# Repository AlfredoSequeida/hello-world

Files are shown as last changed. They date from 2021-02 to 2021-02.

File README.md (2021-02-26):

[Check out the video!](https://youtu.be/ratVGRWkmX0)

# Hello world!

Hello world image demo



This is a 3d printed "hello world!" sign powered by the L0L1n/NodeMCU V3 board, which hosts the ESP8266E board. All of the code, schematics, openSCAD (3D model), and mechanical drawings for the project are open-source for you to modify however you want.

## The model
The model for this design was made using openSCAD. Each letter is meant to be printed individually and then glued together. Because of this, each letter has been split into a module in the openSCAD code. Each letter is between 59.9mm and 205.10mm in length, 184.10mm and 193.3mm in width and 50mm in height in horizontal (laying down) orientation. This model was built with the thought in mind of mounting the letters on a wall, which is why 4 of the letters ("h", "o1", "w", "!", where a letter followed by an integer defines the letter in position to the whole phrase "hello world". Making "o1" the first "o" in "hello") have holes for a screw or nail. With that said, with the letters mounted on the wall split into two rows of the words "hello" and "world!", this entire sign measures a maximum of 790.5mm X 384.2mm X 50 mm (l X w X h) with the letters standing up mounted on a wall.

Every model also has an insert, which is a very thin copy of the letter with half the laying down height which serves as both a cover and a light defuser for the LEDs:

Insert Demo

The inserts fit snug into the letters with a 0.5mm gap, however, you might want to use some sandpaper or a file to create a little more room for letters like the "e", "o", and "d", which have center cutouts since those parts might be a bit more difficult to fit easily.

## Modifying the model
If you want to change the size of the model, this can easily be achieved by changing the attributes at the top of the openSCAD code. All of the measurements are unitless, but mm should be used as those are the units used to measure the electrical components.

`font_size`: The size of the font.

`height`: The height/depth of the model laying down +10mm, so 40mm makes the depth 50mm.

`wall`: The thickness of the walls -5mm, so 10mm makes the walls 5mm thick.

If the size is adjusted, the position of the LED pass through-holes should be modified as well. The same applies to the horizontal and vertical positions of the letters (`h_x`, `w_y`, etc).

The strange adding and subtracting of magical numbers in the measurements is due to the way the walls were created with [openSCAD'S Minkowski method](https://en.wikibooks.org/wiki/OpenSCAD_User_Manual/Transformations#minkowski).

## Printing the model
In the build for the video, this model was printed using a [Creality Ender3 V2](https://www.amazon.com/Creality-Meanwell-Motherboard-Carborundum-Platform/dp/B08D65ZH5W) with an extruder temperature of 225°C and base temperature of 70°C. Using 5% infill with a wall height of 0.28mm using white Inland PLA+. Each Letter took a maximum of 20 hours to print (the "w" took the longest time) and each insert took about 3 hours to print.

## The Parts used
The following parts (electrical components) were used for this build:
- (2) [WS2812B LED Strip 5m 60leds/m](https://www.amazon.com/BTF-LIGHTING-Flexible-Individually-Addressable-Non-waterproof/dp/B01CDTEJBG)
- (1) [LOL1n/NodeMCU V3 (ESP8266E) board](https://www.amazon.com/HiLetgo-Internet-Development-Wireless-Micropython/dp/B010N1SPRK)
- (1) [LM2596S DC-DC 3A Buck Adjustable Step-down Power Supply Converter Module](https://www.amazon.com/Adjustable-Converter-1-5-35v-Efficiency-Regulator/dp/B07QKHR6PY) Used to step down the voltage to 5V if using a power supply larger than 5V.
- (1) [DC Female adapter](https://www.amazon.com/Ksmile®-Female-2-1x5-5mm-Adapter-Connector/dp/B015OCV5Y8)
- (1) [300 - 500 ohm resistor or combination of resistors to make the needed sum](https://www.amazon.com/Elegoo-Values-Resistor-Assortment-Compliant/dp/B072BL2VX1) To protect the first LED when controlling the strip.
- Wire, soldering iron, solder, shrink tube, and connectors to put everything together. With the exception of the wiring, the other parts are optional but recommended.

Included in the assets directory are SVG [schematics](https://github.com/AlfredoSequeida/hello-world/blob/main/assets/schematics.svg) for putting the parts together and [mechanical drawings](https://github.com/AlfredoSequeida/hello-world/blob/main/assets/mechanical_drawings.svg) for the parts. Since they are SVG files, you can open them using a vector editing program like [inkscape](https://inkscape.org/) or a modern web browser and zoom in very close without losing detail.

## The software
The software is controlled via the web interface hosted by the server on the ESP8266 board. To get the software on the board, it needs to be compiled and uploaded to the board using the [Arduino IDE](https://github.com/arduino/Arduino) or [arduino-cli](https://github.com/arduino/arduino-cli). To do this, you must install the [ESP8266 core for Arduino](https://github.com/esp8266/Arduino) and these other dependencies not included with the ESP8266 core:

- [ArduinoJson](https://github.com/bblanchon/ArduinoJson): Used for handling the data sent via HTTP from the web application.
- [FastLED](https://github.com/FastLED/FastLED) : Used to control the LED strip.

The code should also be modified using your local network's (WiFi) AP name and password. This can be set by modifying the character pointers `const char* ssid` and `const char* password`.

Then the LEDs can be controlled using the web interface accessible using a web browser using the IP address of the ESP8266 board after it has been connected to your network.

## The web interface
Web Interface Demo

The web interface is how you can control the LED colors, gradients, and animations of the LEDs. The interface is pretty self-explanatory, however, some of the logic behind it might be useful to explain for modification purposes. All of the HTML, CSS, and JavaScript for the web app can be found in the [index.h](https://github.com/AlfredoSequeida/hello-world/blob/main/ESP8266/LEDController/index.h) file.

The gradients used for the lights are dynamically created at run time and are made using the CSS linear-gradient() function. This makes it easy to create gradients using CSS instead of using FastLED's method for creating gradients. The conversion to something FastLED can understand is handled using JavaScript and then sent over an HTTP POST request to the server as a JSON object with the following format to the `/set-gradient-color` endpoint.

```
{
   "gradient":[
      [
         0,
         255,
         0,
         0
      ],
      [
         255,
         0,
         0,
         255
      ]
   ],
   "brightness":255,
   "animated":true
}
```

`gradient`: Array of arrays containing FastLED formatted gradient.

`brightness` : Integer containing FastLED formatter brightness value.

`animated`: Boolean value declaring if the gradient should be animated or not.

Thank you to Simon R. for his open-source project [pickr](https://github.com/Simonwep/pickr), which provides the color picker for the web app.

## Other notes
The wiring can be made a lot cleaner by rerouting the DC power input to the "W", where all of the electronic components are mounted. However, for my purposes, the exclamation point made a better location for the power input.

You can also use other LED strips, however, the software will need to be modified, and the [chipset must be supported by FastLED](https://github.com/FastLED/FastLED/wiki/Overview#chipsets). Note that the LEDs used in this project were used because they are individually addressable meaning that each LED can be controlled independently of the others, making it possible to create moving animations and gradients with the LEDs.

The font used for the model is [Nooble Wooble](https://www.dafont.com/nooble-wooble.font)

DISCLAIMER: Links included might be affiliate links. If you purchase a product with the links that I provide, I may receive a small commission. There is no additional charge to you!

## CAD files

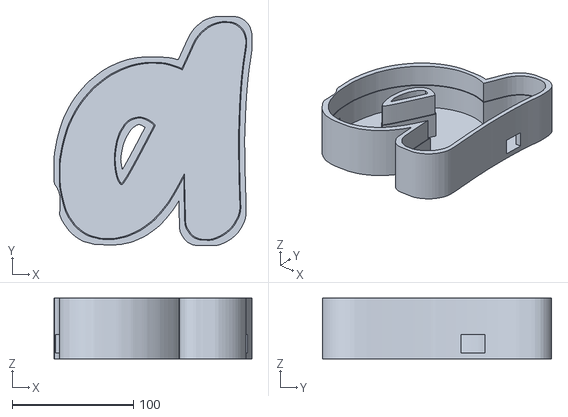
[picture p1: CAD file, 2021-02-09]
models/d.stl
163.3 x 189.0 x 50.0

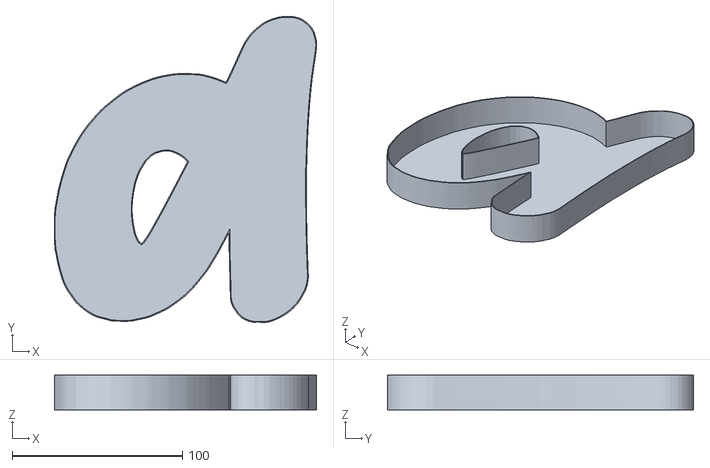
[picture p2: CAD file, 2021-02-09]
models/d_insert.stl
154.2 x 179.9 x 20.4

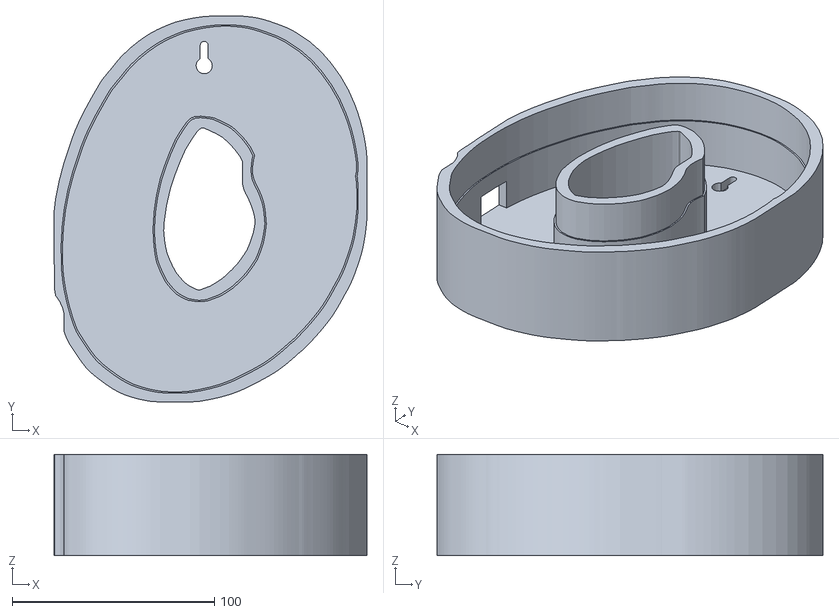
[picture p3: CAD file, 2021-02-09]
models/o1.stl
154.7 x 190.9 x 50.0

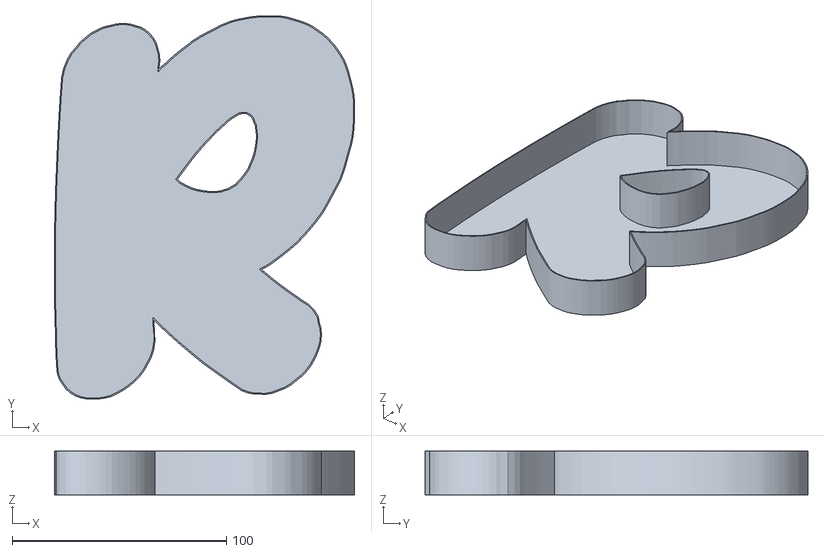
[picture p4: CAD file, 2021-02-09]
models/r_insert.stl
140.1 x 178.6 x 20.4

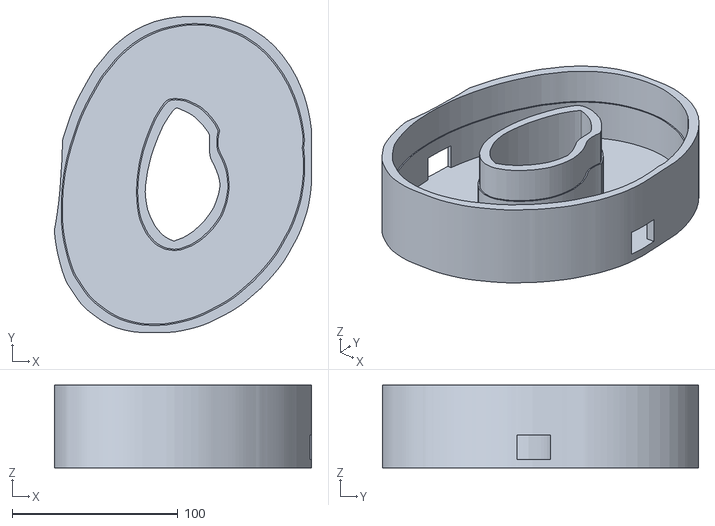
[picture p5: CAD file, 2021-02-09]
models/o.stl
155.4 x 190.9 x 50.0

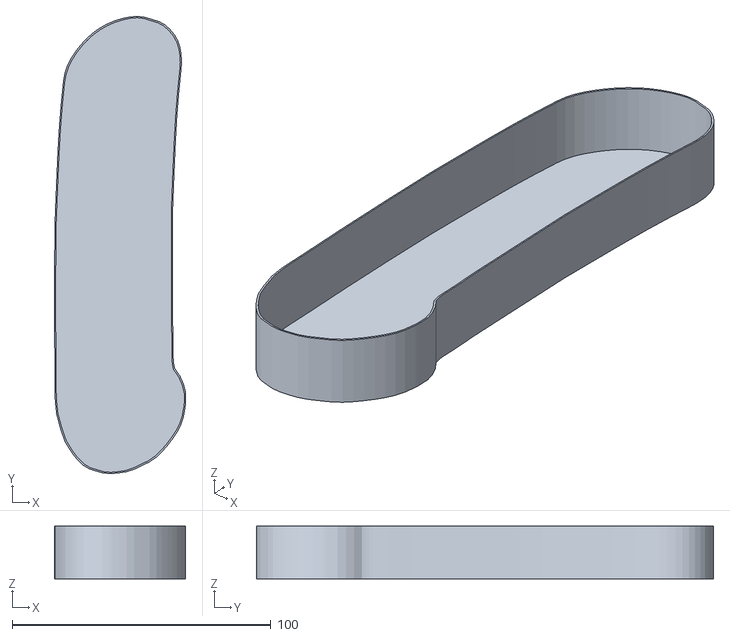
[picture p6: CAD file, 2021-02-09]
models/l1_insert.stl
50.6 x 176.6 x 20.4

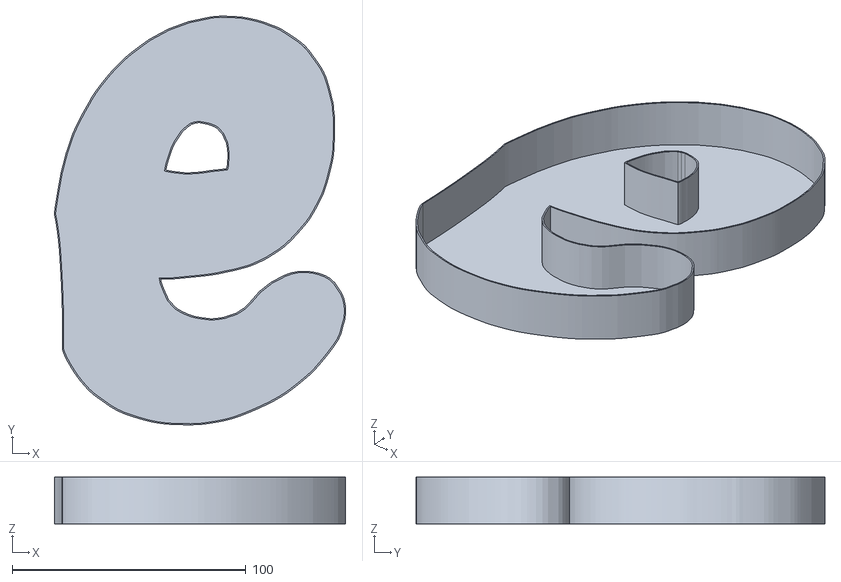
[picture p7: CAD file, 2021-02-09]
models/e_insert.stl
124.6 x 175.0 x 20.0

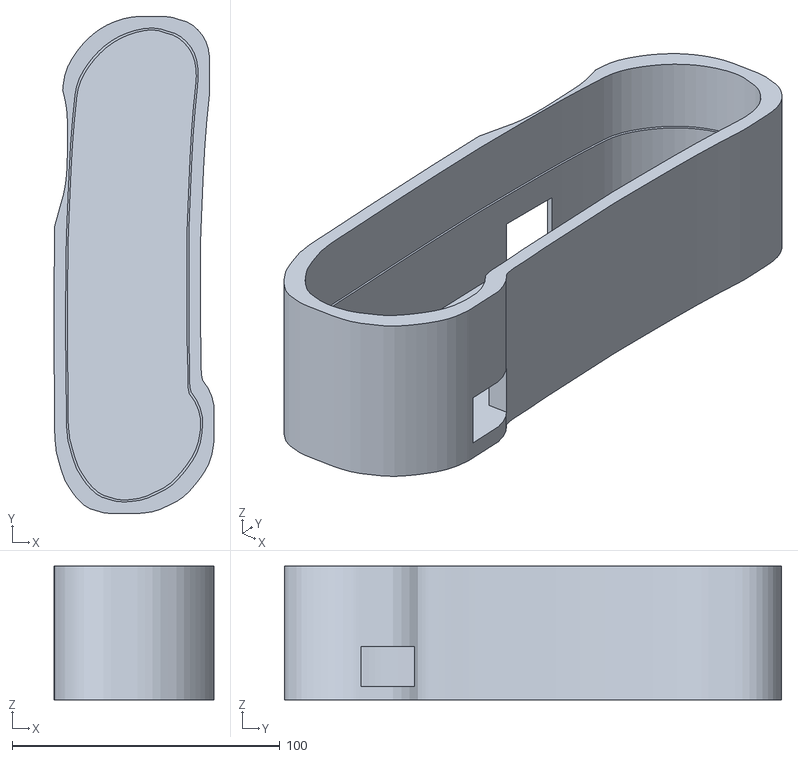
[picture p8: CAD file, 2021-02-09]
models/l3.stl
59.7 x 185.7 x 50.0

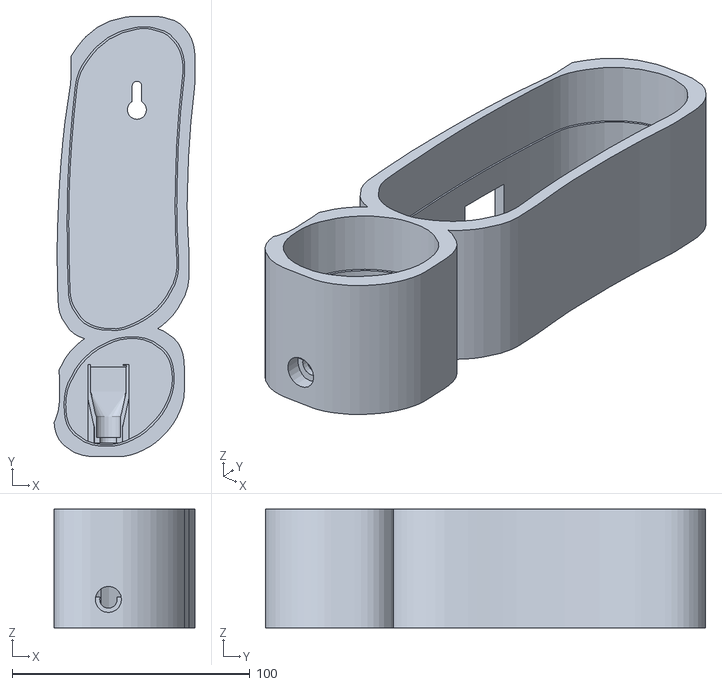
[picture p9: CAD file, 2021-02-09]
models/exclamation.stl
59.3 x 185.0 x 50.0

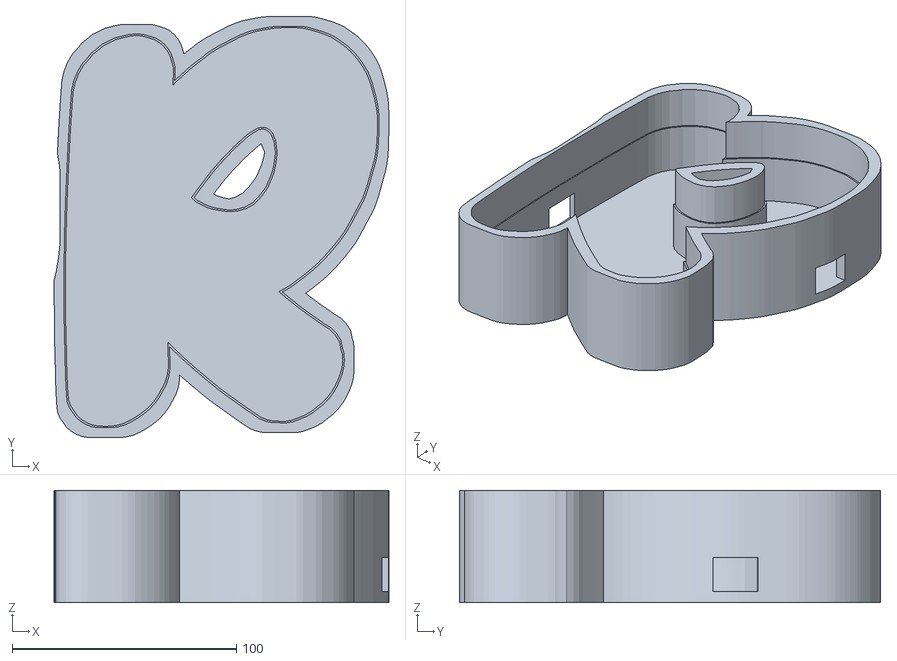
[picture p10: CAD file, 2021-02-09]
models/r.stl
149.2 x 187.7 x 50.0

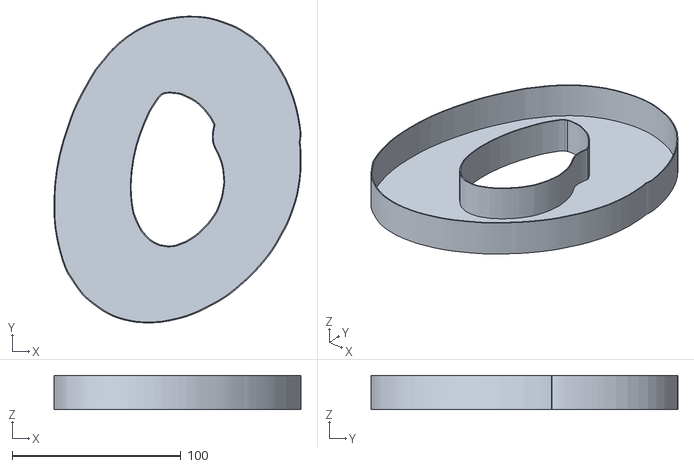
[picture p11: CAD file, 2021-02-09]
models/o2_insert.stl
146.4 x 181.8 x 20.4

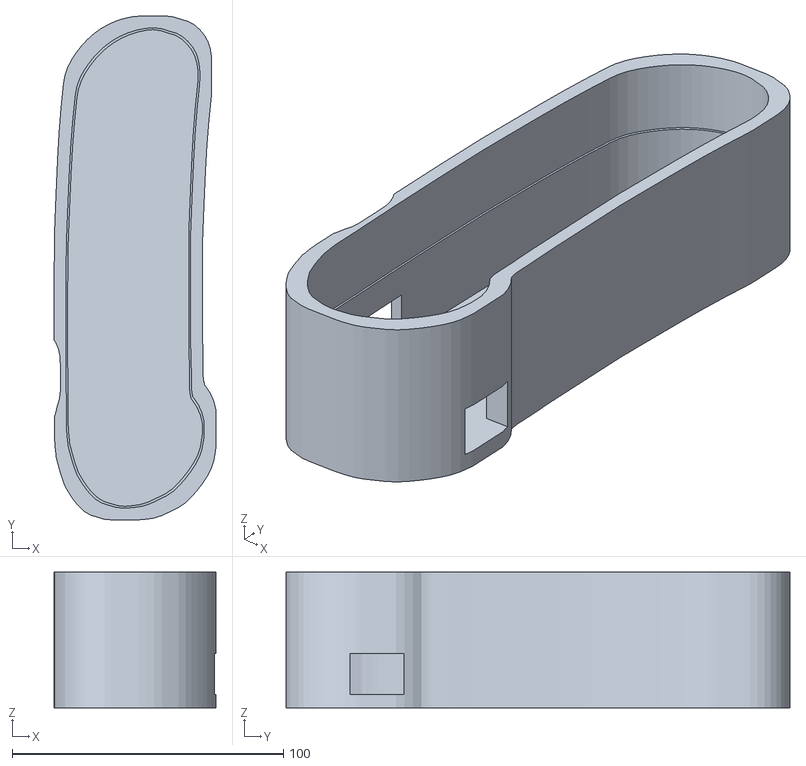
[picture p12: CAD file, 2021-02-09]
models/l1.stl
59.7 x 185.7 x 50.0

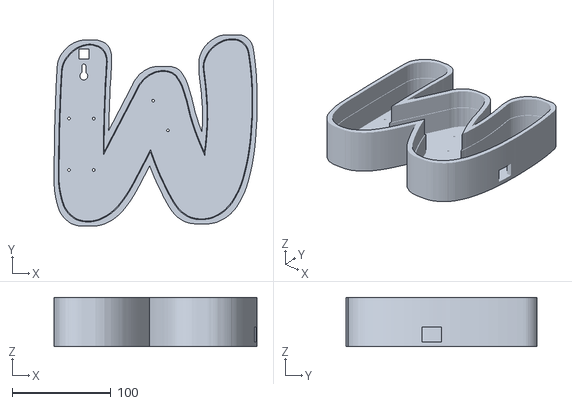
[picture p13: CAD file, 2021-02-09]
models/w.stl
205.1 x 193.3 x 50.0

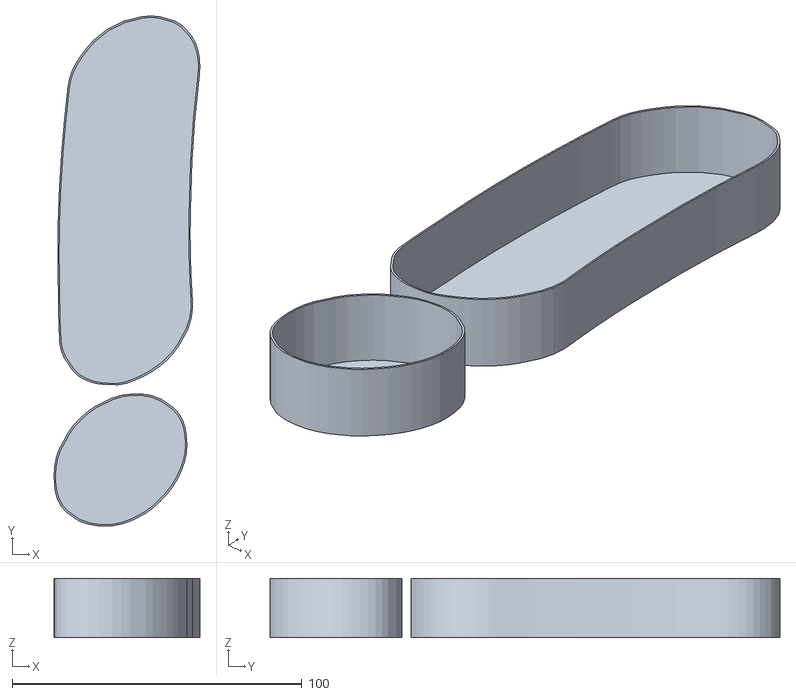
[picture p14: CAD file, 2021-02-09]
models/exclamation_insert.stl
50.3 x 175.9 x 20.4

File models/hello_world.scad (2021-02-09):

$fn = 20;

font = "Nooble Wooble";
height = 40;
font_size = 180;

wall = 10;

// inserts
// adding 0.1 because different letters have different
// curves and thicknesses, so 0.1 allows some room for that
// the excess can be trimmed after printing if necessary.

insert_wall = 0.8 + 0.1;
insert_height = height/2;
insert_support_wall_sub = 1;

// distance difference for insert support = 1 mm
// this leaves a gap of insert 
// wall - 1.3mm leaves 0.5mm gap for the 0.8mm insert

support_wall_sub = wall - 1.3;

// bottom letters are thicker to support
// the top letters

bottom_height = height *2;

led_length = 20;
led_width = 30;
//led_height = height;
led_height = 15;

//cable pass trhough hole from top to bottom
pass_through_length = 10;
pass_through_width = 10;

h_x = 0;
e_x = 135;
l1_x = 268;
l2_x = 325;
o1_x = 379;

w_y = -190;
w_z = 0;

o2_x = 200;
o2_y = w_y; 

r_x = 353;
r_y = w_y;

l3_x = 497;
l3_y = w_y;

d_x = 552;
d_y = w_y;

exclamation_x = 703;
exclamation_y = w_y;

wall_mount_y_top = 120;
wall_mount_y_bottom = -85;

h();
//e();
//l1();
//l2();
//o1();

//w();
//o2();
//r();
//l3();
//d();
//exclamation();

//inserts
//h_insert();
//e_insert();
//l1_insert();
//l2_insert();
//o1_insert();

//w_insert();
//o2_insert();
//r_insert();
//l3_insert();
//d_insert();
//exclamation_insert();

// wall mount test
//difference(){
//    cube([20,20,5]);
//    translate([10,6,0])
//    wall_mount_hole();
//}

//lol1n hole test
//difference(){
//    cube([30,60,5]);
//    
//    translate([2.5,4,0])
//    lol1n_holes();
//}

module h(){
    difference(){
        letter("h",
               font,
               font_size,
               height,
               wall,
               support_wall_sub);
        
        translate([e_x - led_width/2 ,15,0])
        cube([led_width,led_length,led_height]);
        
        translate([20,-38,- wall])
        cube([pass_through_width,
              pass_through_length,
              height]);
        
        translate([25,wall_mount_y_top,0])
        wall_mount_hole();
    }
}

module h_insert(){
    letter("h",
       font,
       font_size,
       height,
       insert_wall);
}

module e(){
    difference(){
        // h and e cross section
        translate([e_x,0,0])
        letter("e",
               font,
               font_size,
               height,
               wall,
               support_wall_sub);
        
        letter("h",
               font,
               font_size,
               height,
               wall,
               support_wall_sub,
               hollow=false);
        
        translate([l1_x - led_width/2 ,0,0])
        cube([led_width,led_length,led_height]);
    }
}

module e_insert(){
    difference(){
        minkowski(){
            difference(){
                translate([e_x,0,0])
                make_text("e",
                          font,
                          font_size,
                          insert_height);

                letter("h",
                       font,
                       font_size,
                       height,
                       wall,
                       hollow=false);
            }
            
            cube(insert_wall, center=true);
        }
        
    minkowski(){
        difference(){
            translate([e_x,0,0])
            make_text("e",
                      font,
                      font_size,
                      insert_height);

            letter("h",
                   font,
                   font_size,
                   height,
                   wall,
                   hollow=false);
            }

    }
        translate([font_size*2 - font_size*2/2,
                   0,
                   height/2])
        cube([font_size*2,font_size*2,insert_wall+0.001],true);
    }
}

module l1(){
    difference(){
        // h and e cross section
        translate([l1_x,0,0])
        letter("l",
               font,
               font_size,
               height,
               wall,
               support_wall_sub);
        
        translate([e_x,0,0])
        letter("e",
               font,
               font_size,
               height,
               wall,
               support_wall_sub,
               hollow=false);
        
        translate([l1_x - led_width/2 ,0,0])
        cube([led_width,led_length,led_height]);
        
        translate([l2_x - led_width/2 ,-20,0])
        cube([led_width,led_length,led_height]);
    }
}

module l1_insert(){
    translate([l1_x,0,0])
    letter("l",
       font,
       font_size,
       height,
       insert_wall);
}

module l2(){
    difference(){
        // h and e cross section
        translate([l2_x,0,0])
        letter("l",
               font,
               font_size,
               height,
               wall,
               support_wall_sub);
        
        translate([l1_x,0,0])
        letter("l",
               font,
               font_size,
               height,
               wall,
               support_wall_sub,
               hollow=false);
        
        translate([l2_x - led_width/2 ,-20,0])
        cube([led_width,led_length,led_height]);
        
        translate([o1_x - led_width/2 ,20,0])
        cube([led_width,led_length,led_height]);
    }
}

module l2_insert(){
    translate([l2_x,0,0])
    letter("l",
       font,
       font_size,
       height,
       insert_wall);
}

module o1(){
    difference(){
        // h and e cross section
        translate([o1_x,0,0])
        letter("o",
               font,
               font_size,
               height,
               wall,
               support_wall_sub);
        
        translate([l2_x,0,0])
        letter("l",
               font,
               font_size,
               height,
               wall,
               support_wall_sub,
               hollow=false);
        
        translate([o1_x - led_width/2 ,20,0])
        cube([led_width,led_length,led_height]);
        
        translate([o1_x+ 70,wall_mount_y_top,0])
        wall_mount_hole();
    }
}

module o1_insert(){
    translate([o1_x,0,0])
    letter("o",
       font,
       font_size,
       height,
       insert_wall);
}

module w(){
    difference(){
        translate([0,w_y,w_z])
        letter("w",
               font,
               font_size,
               height,
               wall,
               support_wall_sub);
        
        translate([o2_x - 20 ,o2_y + 30,0])
        cube([led_width,led_length,led_height]);
        
        translate([20,-68,-wall])
        cube([pass_through_length,
              pass_through_width,
              height]);

        translate([95, w_y+80,0])
        LM2596_holes();
        
        translate([10,w_y+10,0])
        lol1n_holes();
        
        translate([25,wall_mount_y_bottom,0])
        wall_mount_hole();
    }
    

}


module w_insert(){
    translate([0,w_y,0])
    letter("w",
       font,
       font_size,
       height,
       insert_wall);
}


module o2(){
    difference(){
        // h and e cross section
        translate([o2_x,o2_y,0])
        letter("o",
               font,
               font_size,
               height,
               wall,
               support_wall_sub);
        
        translate([0,w_y,0])
        letter("w",
               font,
               font_size,
               height,
               wall,
               support_wall_sub,
               hollow=false);
               
        translate([o2_x - 20 ,o2_y + 30,0])
        cube([led_width,led_length,led_height]);
        
        translate([r_x - led_width/2 ,r_y + 35,0])
        cube([led_width,led_length,led_height]);
    }
    

}

module o2_insert(){
    translate([o2_x,o2_y,0])
    letter("o",
       font,
       font_size,
       height,
       insert_wall);
}

module r(){
    difference(){
        // h and e cross section
        translate([r_x,r_y,0])
        letter("r",
               font,
               font_size,
               height,
               wall,
               support_wall_sub);
        
        translate([o2_x,o2_y,0])
        letter("o",
               font,
               font_size,
               height,
               wall,
               support_wall_sub,
               hollow=false);
               
        translate([r_x - led_width/2 ,r_y + 35,0])
        cube([led_width,led_length,led_height]);
        
        translate([l3_x - 20 ,l3_y + 70,0])
        cube([led_width,led_length,led_height]);
    }
}

module r_insert(){
    translate([r_x,r_y,0])
    letter("r",
       font,
       font_size,
       height,
       insert_wall);
}
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

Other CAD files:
models/l2_insert.stl
models/l3_insert.stl
models/o1_insert.stl
models/h.stl
models/e.stl
models/h_insert.stl
models/l2.stl
models/w_insert.stl

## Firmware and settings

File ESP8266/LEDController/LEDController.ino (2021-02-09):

#define FASTLED_ALLOW_INTERRUPTS 0

// using the ESP8266 nodemcu pin order
// without this the currently used pin 'D5' corresponds to GPIO pin '14' on an
// ESP8266 board
#define FASTLED_ESP8266_NODEMCU_PIN_ORDER
#include <FastLED.h>

#define NUM_LEDS 300
#define DATA_PIN 5
#define CHIPSET WS2812B
#define COLOR_ORDER GRB

#define DEFAULT_R 255
#define DEFAULT_G 255
#define DEFAULT_B 255

#include <ESP8266WiFi.h>
#include <ESP8266WebServer.h>
#include <ArduinoJson.h>

// this is where the HTML, CSS, and JavaScript for the webapp can be found
#include "index.h"

const char* ssid = "";
const char* password = "";

// LED
CRGB leds[NUM_LEDS];

// color pallet
CRGBPalette16 currentPalette;

// default pallet values
uint8_t paletteIndex = 0;
uint8_t brightness = 255;

bool animated = false;

ESP8266WebServer server(80);

void setup() {
    Serial.begin(115200);
    delay(300);

    // LED setup
    FastLED.addLeds<CHIPSET, DATA_PIN, COLOR_ORDER>(leds, NUM_LEDS);
    FastLED.setBrightness(50);

    // setting the default color on boot
    LEDColor(DEFAULT_R, DEFAULT_G, DEFAULT_B);

    WiFi.begin(ssid, password);

    while (WiFi.status() != WL_CONNECTED) {
    delay(1000);
    }
    
    // home page
    server.on("/", home);

    // server endpoints for HTTP POST requests
    server.on("/set-solid-color", setSolidColor);
    server.on("/set-gradient-color", setGradientColor);

    server.begin();
}
void loop() {
    Serial.println("server running ...");
    server.handleClient();

    if (animated){
        fill_palette(leds,
                     NUM_LEDS,
                     paletteIndex,
                     1,
                     currentPalette,
                     brightness,
                     LINEARBLEND);

        EVERY_N_MILLISECONDS(10){
            Serial.println(paletteIndex);
            paletteIndex++;
        }

        FastLED.show();
    }
}

void home() {
    server.send(200, "text/html", indexHTML); 
}

/*
handle color change request
@return void
*/
void setSolidColor() {
    server.sendHeader("Access-Control-Allow-Origin", "*");

    // solid colors are not animated
    animated = false;

    if (server.hasArg("plain")){
        DynamicJsonDocument doc(1024);
        deserializeJson(doc, server.arg("plain"));
        JsonObject body = doc.as<JsonObject>();

        int r = body[String("r")];
        int g = body[String("g")];
        int b = body[String("b")];

        LEDColor(r,g,b);
        server.send(200);
    }
    else{
        server.send(400);
    }
}

/*
handle gradient color change request
@return void
*/
void setGradientColor(){
    server.sendHeader("Access-Control-Allow-Origin", "*");

    if (server.hasArg("plain")){
        DynamicJsonDocument doc(1024);
        deserializeJson(doc, server.arg("plain"));
        JsonObject body = doc.as<JsonObject>();

        LEDGradient(body);
        server.send(200);
    }
    else{
        server.send(400);
    }
}

/*
handle page not found
@return void
*/
void handle_NotFound(){
  server.send(404, "text/plain", "Not found");
}

/*
set LED strip color for the entire strip
@param r integer red value (min: 0, max:255)
@param g integer green value (min: 0, max:255)
@param b integer blue value (min: 0, max:255)
*/
void LEDColor(int r, int g,int b){
    fill_solid(leds, NUM_LEDS, CRGB(r,g,b));
    FastLED.show();
}

/*
set LED gradient color, brightnes, and animation
@param gradient the JsonObject containing the gradient information
*/
void LEDGradient(JsonObject gradient){
    // each gradient index has 4 values
    // 1) the index itself
    // 2) the red value
    // 3) the green value
    // 4) the blue value

    int values = 4;
    int gradientSize = gradient["gradient"].size();
    int numOfIndex = gradientSize * values;
    int maxPaletteIndex = 255;
    
    animated = gradient["animated"];
    brightness = gradient["brightness"];

    typedef unsigned char byte;
    byte bytes[numOfIndex];

    int indexNum = 0;
    for (int j = 0; j < gradientSize; j++){
        for (int k = 0; k < values; k++){
            bytes[indexNum] = gradient["gradient"][j][k];
            indexNum ++;
        }
    }

    // update pallet with gradient info
    currentPalette.loadDynamicGradientPalette(bytes);
    
    fill_palette(leds,
                 NUM_LEDS,
                 paletteIndex,
                 1,currentPalette,
                 brightness,
                 LINEARBLEND);

    FastLED.show();
}

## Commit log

2021-02-09 updated insert demo link
2021-02-09 changed file structure and added missing openscad file
    [d.stl, d_insert.stl, e.stl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]
2021-02-09 updated schematics - added resistor
2021-02-09 updated schematics - converted all objects to path

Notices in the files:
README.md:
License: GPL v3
